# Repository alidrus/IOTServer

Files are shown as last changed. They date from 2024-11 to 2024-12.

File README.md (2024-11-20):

# IoT Climate Control for Wall-Mounted Air Conditioner




---

## Introduction

Wall-mounted air conditioners are convenient and widely used appliances, but they often struggle with inefficiencies that affect both comfort and energy consumption. This project introduces an intelligent, IoT-based climate control system that optimizes air conditioner operation by addressing these inefficiencies.

---

## Problem Statement

Wall-mounted air conditioners rely on temperature probes located near their intake vent—typically high up on the wall. This design introduces two significant issues:

1. **Inaccurate Temperature Measurement**
   The temperature probe measures air closer to the ceiling, which is unrepresentative of the room's true ambient temperature, especially at the human comfort level. This can result in difficulty achieving the desired room temperature, leading to:
   - Overcooling or overheating.
   - The compressor running for extended periods without reaching the target.

2. **Excessive Energy Consumption**
   Prolonged compressor operation leads to skyrocketing electricity costs, especially in regions where energy prices are high. This inefficiency stems directly from the flawed measurement setup.

---

## The Solution

This project provides a **wall-mounted climate control device** designed to address these challenges. The device is installed on the wall opposite the air conditioner's blower unit and features the following:

- **Integrated Temperature/Humidity Sensor:** Positioned at chest level to provide accurate, representative readings of the room's temperature and humidity.
- **Compressor Control:** Intelligently manages the air conditioner’s compressor to optimize runtime and minimize energy consumption.
- **Energy Efficiency:** By preventing unnecessary compressor operation, this device significantly reduces energy usage without compromising comfort.
- **IoT Integration:** Enables remote monitoring and control of the air conditioner through an easy-to-use web interface.

---

## Features

- **Energy Savings:** Prevents overuse of the compressor by ensuring optimal runtime.
- **Accurate Temperature Monitoring:** Uses a DHT22 (or similar) temperature/humidity sensor to track the room's environmental conditions.
- **Web Control:** Includes a user-friendly interface for setting temperature thresholds and monitoring system status.
- **Customizable and Open Source:** Fully open-source project based on the ESP32, allowing customization and contributions.

### Physical Prototype Circuit
Here’s a picture of the physical prototype circuit built for this project:
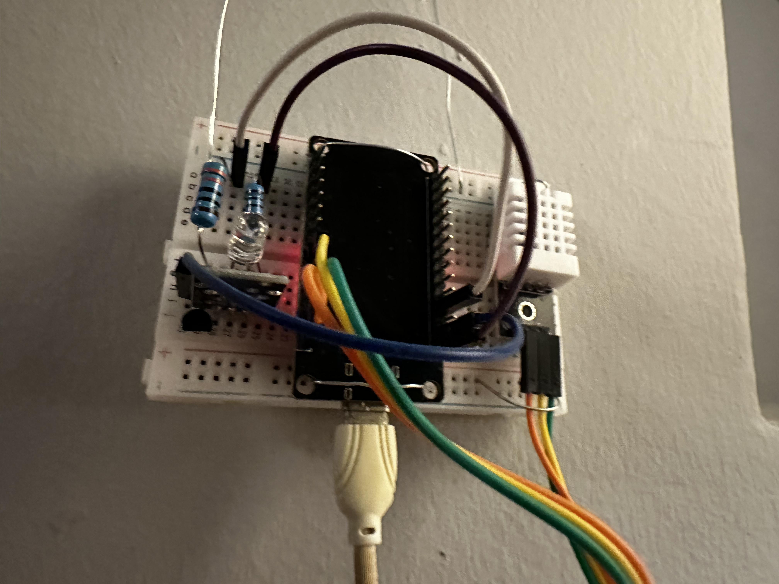
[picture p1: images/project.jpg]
Prototype Circuit


---

## Bill of Materials (BOM)

To build this climate control device, you will need the following components:

- **ESP32 Board**: Any ESP32-based development board will work. (This project uses the 30-pin ESP-32-WROOM.)
- **2N2222 NPN Transistor**: Used to drive the IR LED for communication with the air conditioner.
  - **Why a Transistor Is Necessary:**
    1. The GPIO pin on the ESP32 can only supply limited current (typically 20mA, max 40mA), which is insufficient to drive the IR LED effectively.
    2. Overloading the GPIO pin could damage the ESP32.
    3. The transistor acts as a switch, allowing the IR LED to draw sufficient current directly from the power supply without affecting the GPIO pin.
- **330 Ω Resistor**: Limits the base current to the 2N2222 transistor.
- **10 Ω Resistor**: Limits current through the IR LED to prevent damage.
- **IR LED**: Transmits signals to the air conditioner. Connect between the 10 Ω resistor and the collector of the 2N2222.
- **DHT22 Sensor**: Combines temperature and humidity sensing for environmental readings.
- **5V DC Power Supply (1A recommended):** Powers the ESP32 and associated circuitry.

---

### IR LED Driver Circuit Schematic
Below is the schematic of the IR LED driver circuit used to transmit signals to the air conditioner:
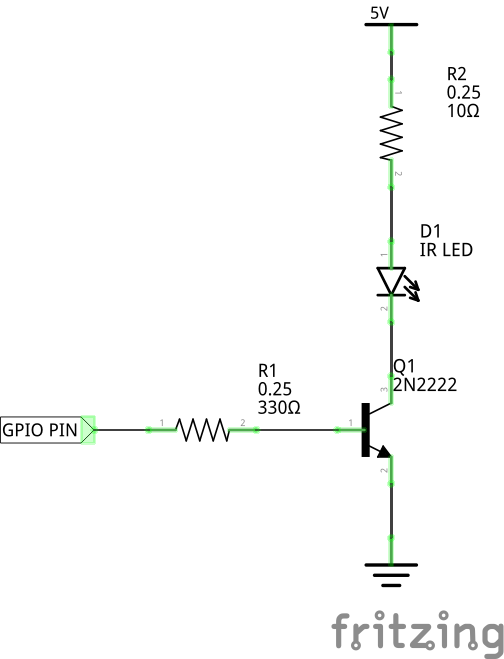
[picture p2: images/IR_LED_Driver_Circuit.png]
IR LED Driver Circuit


---

## Web Interface

The device features an intuitive web interface for monitoring and controlling the air conditioner.
Here’s a screenshot of the web interface:
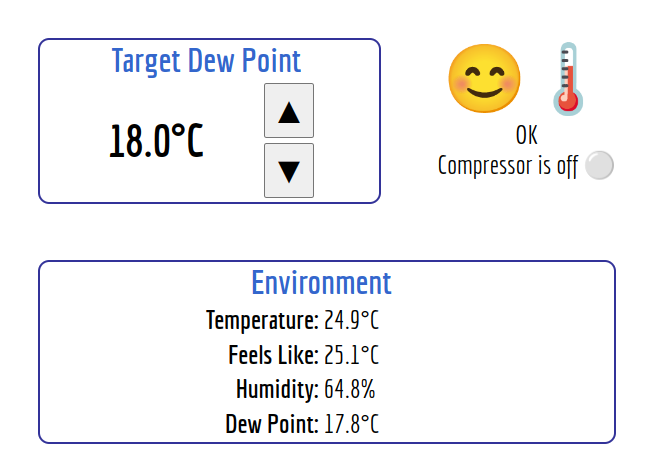
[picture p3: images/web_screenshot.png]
Web Interface


---

## Getting Started

### Hardware and Software Requirements

You will need the following tools to set up and deploy this project:

- A computer running Mac OS or Linux (tested on Ubuntu 24.04).
- [ESP32 Microcontroller Board](https://www.espressif.com/en/products/socs/esp32).
- [Arduino CLI](https://github.com/arduino/arduino-cli) for uploading the firmware.
- [Node.js](https://nodejs.org/en/) and npm or yarn for compiling the web interface.

---

### Setup Instructions

1. **Clone and Compile the Project:**
   ```bash
   git clone https://github.com/alidrus/IOTServer.git
   cd IOTServer
   ```

2. **Install node modules needed to build `IndexHtml.h`:**
   Navigate to the `web` folder and install dependencies:
   Using `npm`:
   ```bash
   cd web
   npm install
   ```
   Using `yarn`:
   ```bash
   cd web
   yarn install
   ```

3. **Compile:**
   Use `make` to compile the project:
   ```bash
   make
   ```
   You may be prompted to provide additional information such as the
   temperature calibration value, the pin that the DHT22 sensor is connected
   to, the IR transmitter pin (the one that leads into the 2N2222's collector),
   WiFi hostname, WiFi SSID and WiFi password. This will only happen the first
   time you run make.
   ```
   $ make
   Hostname of ESP32: iotserver
   WiFi SSID: myiot
   WiFi Password: mypassword
   Which pin is the DHT humidity and temperature sensor connected to? 17
   Which pin is the infra-red LED connected to? 12
   Temperature calibration amount (e.g. 1.2f): -1.2f
   ```

4. **Upload to ESP32:**
   Use `make upload` to flash it to your ESP32:
   ```bash
   make upload
   ```

---

## How It Works

1. The system continuously monitors the room’s actual temperature and humidity using the onboard sensor.
2. Based on the desired temperature threshold set by the user, the device sends IR signals to the air conditioner to control its operation.
3. Intelligent control prevents the compressor from running unnecessarily, conserving energy while maintaining comfort.

---

## Roadmap

- Add support for **Google Home integration**.
- Develop a **more advanced web interface**.
- Integrate **power monitoring** to track energy usage and savings.
- Enable **Home Assistant integration** for expanded automation possibilities.

---

## Contributing

Contributions are welcome! If you have ideas or suggestions to improve this project, feel free to open an issue or submit a pull request.

---

## License

This project is licensed under the MIT License - see the [LICENSE](LICENSE) file for details.

---

## Acknowledgments

Special thanks to everyone in the open-source community for their support and contributions.

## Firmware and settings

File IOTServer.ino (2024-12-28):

// vim: syntax=arduino autoindent expandtab tabstop=4 shiftwidth=4 softtabstop=4:

#include <WiFi.h>
#include <ESPmDNS.h>
#include <NTPClient.h>
#include <AsyncTCP.h>
#include <ESPAsyncWebServer.h>
#include <DHTesp.h>

#include "Hysteresis.h"
#include "IndexHtml.h"
#include "Pins.h"
#include "Secrets.h"
#include "Calibration.h"

#include <IRremote.hpp>

// Comment this line out if you don't want serial console messages
#define DEBUG_MODE

WiFiUDP ntpUDP;

NTPClient timeClient(ntpUDP, "asia.pool.ntp.org", 28800, 60000);

AsyncWebServer server(80);

DHTesp dht;

ComfortState cf;

Hysteresis climateControl;

static const char* okResponse = "HTTP/1.1 200 OK";
static const char* contentHeaderJson = "Content-Type: application/json";
static const char* contentHeaderHtml = "Content-Type: text/html";
static const char* environmentResponse = "{\"ts\": \"%.2f\", \"t\": \"%.2f\", \"h\": \"%.2f\", \"hi\": \"%.2f\", \"dp\": \"%.2f\", \"cs\": \"%s\", \"co\": %s}";

char stringBuffer[112];

bool hysteresisActive = true;

void wifiSetup() {
    // Disconnect from WiFi
    WiFi.disconnect(true, true);

    delay(1000);

    // Set hostname
    WiFi.setHostname(WIFI_HOSTNAME);

    // Set WiFi mode to station
    WiFi.mode(WIFI_STA);

    // WiFi credentials
    WiFi.begin(WIFI_SSID, WIFI_PASSWORD);

#ifdef DEBUG_MODE
    // DEBUG messages on serial console
    Serial.print("Connecting Wifi");
#endif

    int counter = 0;
    while (WiFi.status() != WL_CONNECTED) {
        if (counter > 10) {
            Serial.println("Unable to connect to WiFi!");
            return;
        }

#ifdef DEBUG_MODE
        Serial.print(".");
#endif

        delay(500);

        counter++;
    }

#ifdef DEBUG_MODE
    // DEBUG messages on serial console
    Serial.println("");
    Serial.println("WiFi connected");
    Serial.print("MAC address: ");
    Serial.println(WiFi.macAddress());
    Serial.print("IP address: ");
    Serial.println(WiFi.localIP());
    Serial.print("ESP32 Hostname: ");
    Serial.println(WiFi.getHostname());
    Serial.println("The IOT Server can be accessed via a browser at the following URL:");
    Serial.print("http://");
    Serial.println(WiFi.localIP());
#endif

    // Set up mDNS
    if (!MDNS.begin(WIFI_HOSTNAME)) {
        // Reboot!
        Serial.println("Unable to set up mDNS!");

        return;
    }
}

void webServerSetup() {
#ifdef DEBUG_MODE
    // DEBUG messages on serial console
    Serial.println("Starting server...");
#endif

    // Route for root / web page
    server.on("/", HTTP_GET, [](AsyncWebServerRequest *request) {
        Serial.println("REQUEST: /");

        request->send(200, "text/html; charset=UTF-8", indexHtml);
    });

    // Route for root /index.html
    server.on("/index.html", HTTP_GET, [](AsyncWebServerRequest *request) {
        Serial.println("REQUEST: /index.html");

        request->send(200, "text/html; charset=UTF-8", indexHtml);
    });

    // Route for root /index.css
    server.on("/index.css", HTTP_GET, [](AsyncWebServerRequest *request) {
        Serial.println("REQUEST: /index.css");

        request->send(200, "text/css; charset=UTF-8", indexCss);
    });

    // Route for root /index.css
    server.on("/index.js", HTTP_GET, [](AsyncWebServerRequest *request) {
        Serial.println("REQUEST: /index.js");

        request->send(200, "text/javascript; charset=UTF-8", indexJs);
    });

    // Send power toggle
    server.on("/power", HTTP_GET, [] (AsyncWebServerRequest *request) {
        Serial.println("REQUEST: /power");

        // Power Toggle
        CompressorControl::powerToggle();

        request->send(200, "text/plain", "OK");
    });

    // Increase temperature
    server.on("/temperature/up", HTTP_GET, [] (AsyncWebServerRequest *request) {
        Serial.println("REQUEST: /temperature/up");

        climateControl.incrementTargetDewPoint();

        request->send(200, "text/plain", "OK");
    });

    // Decrease temperature
    server.on("/temperature/down", HTTP_GET, [] (AsyncWebServerRequest *request) {
        Serial.println("REQUEST: /temperature/down");

        climateControl.decrementTargetDewPoint();

        request->send(200, "text/plain", "OK");
    });

    // Activate hysteresis
    server.on("/hysteresis/on", HTTP_GET, [] (AsyncWebServerRequest *request) {
        Serial.println("REQUEST: /hysteresis/on");

        hysteresisActive = true;

        request->send(200, "text/plain", "OK");
    });

    // Deactivate hysteresis
    server.on("/hysteresis/off", HTTP_GET, [] (AsyncWebServerRequest *request) {
        Serial.println("REQUEST: /hysteresis/off");

        hysteresisActive = false;

        request->send(200, "text/plain", "OK");
    });

    // Route for GET request to /environment
    server.on("/environment", HTTP_GET, [](AsyncWebServerRequest *request) {
        Serial.println("REQUEST: /environment");

        TempAndHumidity dhtValues = dht.getTempAndHumidity();

        if (dht.getStatus() != 0) {
            request->send(503, "text/plain", "Service unavailable");
        } else {
            const float targetDewPoint = climateControl.getTargetDewPoint();
            const float temperature = dhtValues.temperature + TEMPERATURE_CALIBRATION;
            const float heatIndex = dht.computeHeatIndex(temperature, dhtValues.humidity);
            const float dewPoint = dht.computeDewPoint(temperature, dhtValues.humidity);
            const float cr = dht.getComfortRatio(cf, temperature, dhtValues.humidity);

            String comfortStatus;

            switch(cf) {
                case Comfort_OK:
                    comfortStatus = "OK";
                    break;
                case Comfort_TooHot:
                    comfortStatus = "Too Hot";
                    break;
                case Comfort_TooCold:
                    comfortStatus = "Too Cold";
                    break;
                case Comfort_TooDry:
                    comfortStatus = "Too Dry";
                    break;
                case Comfort_TooHumid:
                    comfortStatus = "Too Humid";
                    break;
                case Comfort_HotAndHumid:
                    comfortStatus = "Hot and Humid";
                    break;
                case Comfort_HotAndDry:
                    comfortStatus = "Hot and Dry";
                    break;
                case Comfort_ColdAndHumid:
                    comfortStatus = "Cold and Humid";
                    break;
                case Comfort_ColdAndDry:
                    comfortStatus = "Cold and Dry";
                    break;
                default:
                    comfortStatus = "Unknown";
                    break;
            };

            sprintf(stringBuffer, environmentResponse, targetDewPoint, temperature, dhtValues.humidity, heatIndex, dewPoint, comfortStatus, CompressorControl::isOn ? "true" : "false");

            request->send(200, "application/json", stringBuffer);
        }
    });

    // Reply with a 404 error if request does not match anything else
    server.onNotFound([](AsyncWebServerRequest *request) {
        request->send(404, "text/plain", "Not found");
    });

    // Start the server
    server.begin();

#ifdef DEBUG_MODE
    // DEBUG messages on serial console
    Serial.println("Server started");
#endif
}

void setup() {
#ifdef DEBUG_MODE
    // Connect to serial console for DEBUG messages
    Serial.begin(115200);
#endif

    delay(1500);

    // Setup WiFi
    wifiSetup();

    delay(500);

    dht.setup(DHT_PIN, DHTesp::DHT22);

    delay(250);

    // Setup Web Server
    webServerSetup();

    delay(250);

    // Begin time client
    timeClient.begin();

    delay(500);

    // Initialize compressor control class
    CompressorControl::initialize();

    // Create Tasks
    xTaskCreate(multiTask, "Multiple Task", 4000, NULL, 1, NULL);
}

void multiTask(void *parameters) {
    int counter = 0;

    unsigned long rawTime, currentHour;

    while (true) {
        rawTime = timeClient.getEpochTime();

        currentHour = (rawTime % 86400L) / 3600;

        // Check WiFi health and reconnect if needed
        if (WiFi.status() != WL_CONNECTED) {
            wifiSetup();
        }

        // Only perform timesync when connected to WiFi
        if (WiFi.status() == WL_CONNECTED) {
            timeClient.update();
        }

        // Run climate control monitoring every 20 seconds
        if (counter % 20 == 0) {
            bool skipRest = false;
            bool afterHours = currentHour >= 0 && currentHour <= 6;

            TempAndHumidity dhtValues = dht.getTempAndHumidity();

            const float temperature = dhtValues.temperature + TEMPERATURE_CALIBRATION;
            const float dewPoint = dht.computeDewPoint(temperature, dhtValues.humidity);
            const float targetDewPoint = climateControl.getTargetDewPoint();
            const float hysteresisBuffer = climateControl.getHysteresisBuffer();

            // If hysteresis is not being skipped, have the climate control routines monitor the comfort level
            if (!afterHours && hysteresisActive) {
                climateControl.monitorComfort(dewPoint);

                skipRest = true;
            }

            // If the compressor is still on during off hours, turn off the
            // compressor and skip the rest of the climate monitoring if block
            if (!skipRest && (afterHours || !hysteresisActive) && CompressorControl::isOn) {
                CompressorControl::turnOff();

                skipRest = true;
            }

            // If we somehow reached this point during the off hours and the
            // dew point is way below target, it means someone left the AC
            // running and we need to turn off the compressor
            if (!skipRest && (afterHours || !hysteresisActive) && dewPoint < (targetDewPoint - hysteresisBuffer)) {
                CompressorControl::turnOff();

                skipRest = true;
            }
        }

        counter += 1;

        // Idle for the next second
        vTaskDelay(1000 / portTICK_PERIOD_MS);
    }
}

void loop() {}

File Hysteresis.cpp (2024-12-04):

// vim: syntax=arduino autoindent expandtab tabstop=4 shiftwidth=4 softtabstop=4:

#include "Hysteresis.h"

void Hysteresis::monitorComfort(float currentDewPoint) {
    Serial.print("Hysteresis::monitorComfort(");
    Serial.print(currentDewPoint);
    Serial.println(")");

    const unsigned long currentTime = millis(); // Function to get current time in seconds

    if (this->acStartTime == 0) {
        this->acStartTime = currentTime;
    }

    // Determine if hysteresis should be applied
    bool applyHysteresis = (currentTime - this->acStartTime > INITIAL_COOLDOWN_TIME);

    // Check if compressor should be turned ON
    if (currentDewPoint > (this->targetDewPoint + this->hysteresisBuffer)
            && !CompressorControl::isOn
            && (((currentTime - CompressorControl::restStartTime) > MIN_REST_TIME) || !applyHysteresis))
    {
        // Turn compressor ON if heat index is above target and rest time has passed
        CompressorControl::turnOn();

        return;
    }

    // Check if compressor should be turned OFF
    if (CompressorControl::isOn
            && ((applyHysteresis && currentDewPoint < (this->targetDewPoint - this->hysteresisBuffer))  // Apply hysteresis after cooldown time
                || (!applyHysteresis && currentDewPoint < this->targetDewPoint)                         // No hysteresis during initial cooldown
                || ((currentTime - CompressorControl::runStartTime) > MAX_RUN_TIME)))                   // Max runtime safety cutoff
    {
        // Turn compressor OFF if any of the above conditions are met
        CompressorControl::turnOff();

        return;
    }

    // Failsafe to prevent compressor run-on:
    // Compressor was supposedly turned off but the dew point is a lot lower than the threshold
    if (!CompressorControl::isOn && currentDewPoint < (this->targetDewPoint - (1.4 * this->hysteresisBuffer)))
    {
        // Turn compressor OFF and reset compressor rest start time
        CompressorControl::turnOff();

        return;
    }

    // Failsafe to prevent overheating:
    // Compressor was supposedly turned on but the dew point is a lot higher than the threshold
    if (CompressorControl::isOn && currentDewPoint > (this->targetDewPoint + (1.4 * this->hysteresisBuffer)))
    {
        // Turn compressor ON and reset compressor run start time
        CompressorControl::turnOn();

        return;
    }
}

float Hysteresis::getTargetDewPoint() const {
    Serial.println("Hysteresis::getTargetDewPoint()");

    return this->targetDewPoint;
}

float Hysteresis::getHysteresisBuffer() const {
    Serial.println("Hysteresis::getHysteresisBuffer()");

    return this->hysteresisBuffer;
}

void Hysteresis::setTargetDewPoint(float targetDewPoint) {
    Serial.print("Hysteresis::setTargetDewPoint(");
    Serial.print(targetDewPoint);
    Serial.println(")");

    this->targetDewPoint = targetDewPoint;
}

void Hysteresis::incrementTargetDewPoint() {
    Serial.println("Hysteresis::incrementTargetDewPoint()");

    this->targetDewPoint += 0.1;
}

void Hysteresis::decrementTargetDewPoint() {
    Serial.println("Hysteresis::decrementTargetDewPoint()");

    this->targetDewPoint -= 0.1;
}

bool Hysteresis::compressorIsOn() {
    return CompressorControl::isOn;
}

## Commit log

2020-08-06 Removed binary files produced by arduino-cli
2024-08-18 Reversed the definitions of LED_ON and LED_OFF. Defined LED_BUILTIN as 2.
2024-08-18 Adapted to esp32 and added several improvements
2024-08-18 Replaced latest HTML/CSS/Javascript code
    [IOTServer.ino]
2024-08-19 Changed client.println() to a static const char* declaration
2024-08-19 Integrated NTPClient and return current time in JSON response
2024-11-06 Added reading of DHT22 from GPIO26 pin. Changed the content-type of AJAX responses to application/json (was text/html before). Added /temperature and /humidity endpoints
2024-11-07 Added meta tag to set charset to UTF-8. Added missing dewPointReading id. Removed .ledIsOn from the JSON.parse() result. Added units to the readings.
2024-11-07 Replaced old /humidity and /temperature endpoint with a general /environment endpoint with multiple readings and settings
    [IOTServer.ino]
2024-11-07 Do html minification, printify and copy to clipboard within a single script
2024-11-07 Calibrated the temperature reading as reading minus 1 deg C
2024-11-08 Adjusted temperature to -2 of reading
2024-11-08 Remove minified html file after printify script is done
2024-11-08 Adjust thermostat display and buttons
2024-11-08 Added code to temperatureUp and temperatureDown
2024-11-08 Added endpoints /temperature/up and /temperature/down
2024-11-08 Removed printify
2024-11-08 Expose temperatureUp and temperatureDown to the global scope
2024-11-11 Renamed thermostatSetting as heatIndexTarget
2024-11-13 Included Arduino.h to load the typedefs for uint16_t
2024-11-14 Changed name of variable heat index target -> target heat index (sounds better)
2024-11-14 Added buttons for activating cooling mode and fan mode
2024-11-14 Run Hysteresis::monitorComfort() every 20 seconds and track this using the new lastHysteresisTime timestamp
2024-11-15 Included IRremote.h in main script to prevent linking errors
    [IOTServer.ino]
2024-11-15 Removed mode changing web service endpoints. And removed all CompressorControl stuff since it is no longer needed in the main program
    [IOTServer.ino]
2024-11-15 Removed cooling mode and fan mode controls
2024-11-16 Monitor comfort level based on dew point, not heat index
2024-11-16 Minor adjustments, minor bug fixes and whitespace
    [Hysteresis.cpp]
2024-11-16 Added Calibration.h to list of ignored files
2024-11-16 Adjust temperature reading by TEMPERATURE_CALIBRATION degrees
2024-11-16 Added dependency of Calibration.h
2024-11-16 Update the display of the thermostat setting when the up or down button is pressed
2024-11-17 Increment displayed thermostat setting visually as soon as the button is pressed and let it update by itself after that.
2024-11-17 Let the compressor activate if we just turned on the device
2024-11-18 Added failsafe to prevent compressor run-on and also climate overheating
    [Hysteresis.cpp]
2024-11-19 Emphasized that I used arduino-cli
2024-11-19 Updated image of project circuit
2024-11-19 Added schematic for LED driver circuit
2024-11-19 Added Bill of materials and repositioned images
2024-11-20 Added back physical prototype circuit picture, LED driver circuit schematic and web screenshot
2024-11-28 Renamed toggleACOnOff() to powerToggle()
2024-12-28 Added /power API endpoint

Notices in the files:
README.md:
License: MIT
